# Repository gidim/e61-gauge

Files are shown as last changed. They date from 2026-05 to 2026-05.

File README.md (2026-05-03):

# E61 Gauge

An analog temperature gauge for E61 espresso machines. A custom PCB drives a VID6606 stepper motor gauge needle, reading temperature from an NTC thermistor. The gauge connects via BLE to a web app for calibration and real-time monitoring.

The dial has a non-linear scale (0–150°C) with an expanded green zone at 92–97°C for precision in the critical temperature range.

<p align="center">
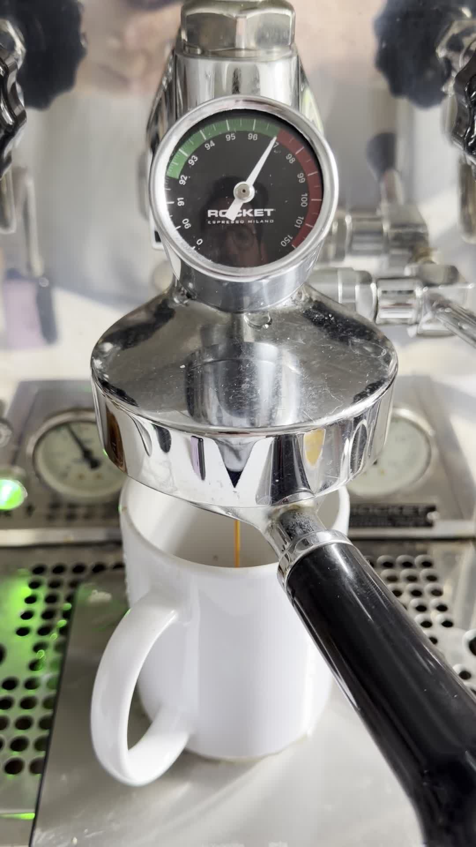
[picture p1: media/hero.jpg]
  
</p>

<p align="center">
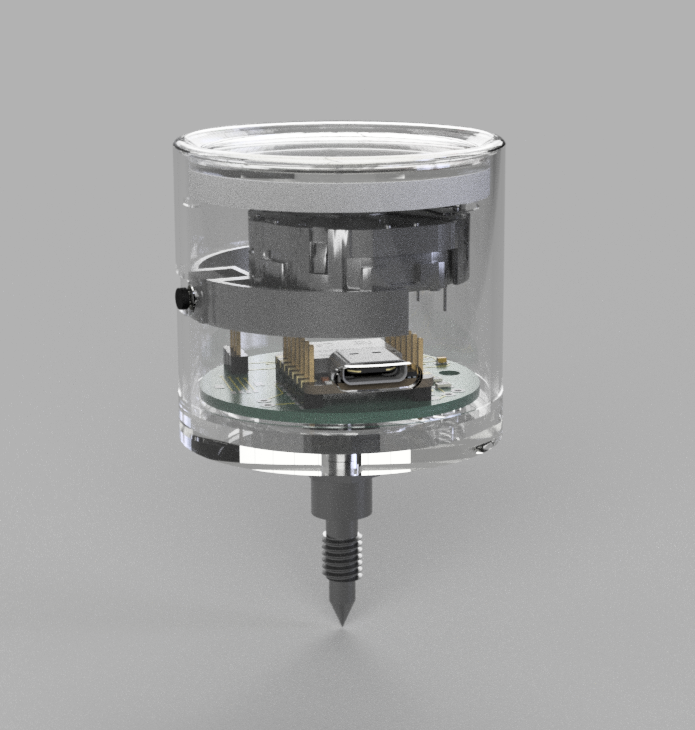
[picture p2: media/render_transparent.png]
  
  &nbsp;
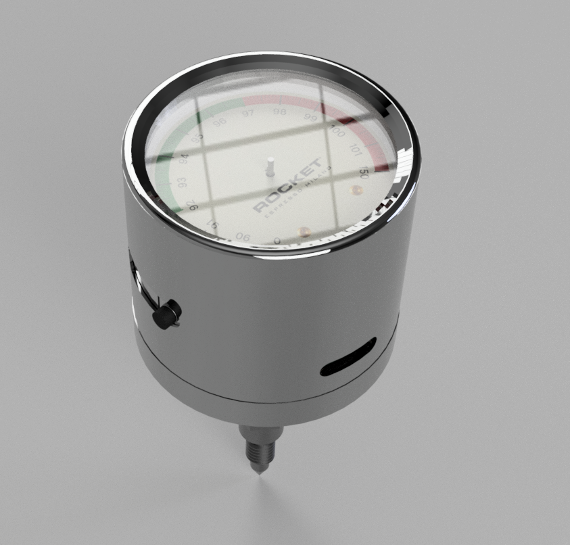
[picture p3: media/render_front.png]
  
  &nbsp;
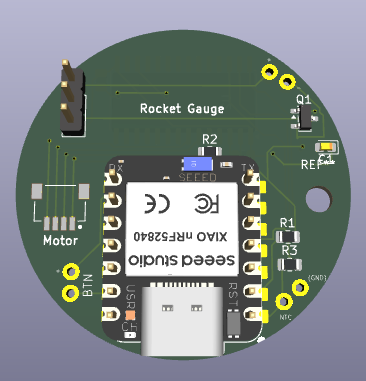
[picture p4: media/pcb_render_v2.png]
  
  &nbsp;
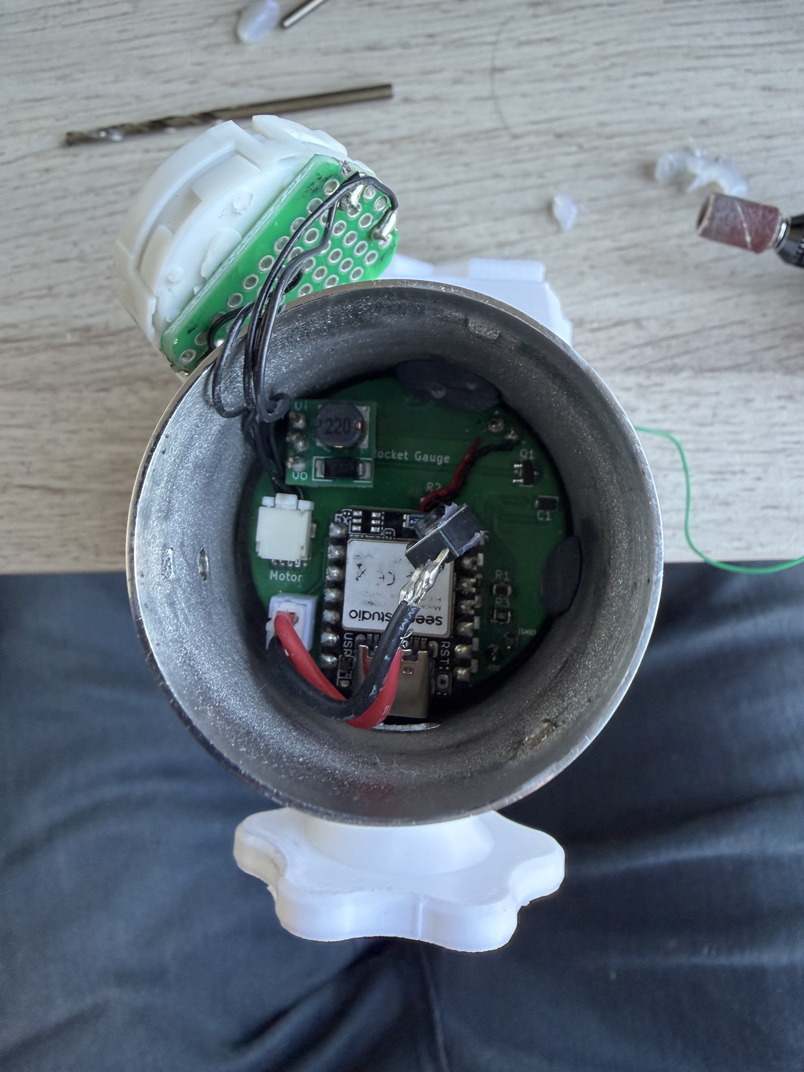
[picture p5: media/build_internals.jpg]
  
</p>

<p align="center">
  <a href="media/demo.mov">▶ Watch demo video</a>
</p>

---

## Hardware

Built around a **Seeed Studio XIAO nRF52840**. Key components:

- VID6606 stepper driver (SOIC-28) driving the gauge needle
- 100kΩ NTC thermistor for temperature sensing
- 2N2222A transistor switching a 5V boost converter
- Momentary button for power management (deep sleep after 10 min idle)
- JST connector for the stepper motor coils

The PCB was custom manufactured and assembled. The dial face is a custom design with a non-linear scale — the green zone (92–97°C) is expanded for precision while the cold and hot extremes are compressed. The SVG is in `hardware/dial_face.svg`. KiCad source files, schematic, and BOM are in `hardware/`.

## Enclosure

The enclosure was SLM (selective laser melting) 3D printed in metal and hand-sanded to achieve the chrome-like finish. Fusion 360 source (`enclosure/gauge_enclosure.f3z`), STEP, and STL files are in `enclosure/`.

### KiCad libraries

The schematic uses two non-standard libraries included in `libraries/`:

- `XIAO_nRF52840.pretty/` — footprint for the XIAO nRF52840 module
- `Seeed_Studio_XIAO_Series/` — schematic symbol

Add both to your KiCad library paths before opening the project.

## Firmware

Arduino sketch in `firmware/gauge/`. Uses the Adafruit nRF52 BSP.

**Dependencies** (install via Arduino Library Manager):
- `Adafruit TinyUSB`
- `Adafruit nRF52` BSP (includes `bluefruit`, `Adafruit_LittleFS`, `InternalFileSystem`)
- `AccelStepper`

The gauge supports BLE serial commands for calibration, homing, sweep tests, and configuration. See `firmware/gauge/commands.h` for the full command set.

## Web App

A Web Bluetooth app in `webapp/` — open `index.html` in Chrome (Android, macOS, or Windows). iOS Safari does not support Web Bluetooth.

Connect to the gauge over BLE to monitor temperature, set calibration points, and control the needle.

## Tools

Python utilities in `tools/` for serial-based development and testing.

```
pip install -r tools/requirements.txt
python tools/serial_terminal.py
```

## vid6606

`vid6606/` contains a standalone sweep demo sketch and a copy of the [SwitecX25](https://github.com/clearwater/SwitecX25) stepper library used for the VID6606 driver.

## test_ntc_sketch

A minimal Arduino sketch for validating NTC thermistor readings independently of the main firmware.

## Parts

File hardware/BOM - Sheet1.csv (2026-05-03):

Reference | Qty | Value | Assembly Status | Exclude from BOM | Footprint | Manufacturer | MPN | Datasheet
Battery1 | 1 | Wire Connection | DNP/Hand Solder |  | TestPoint:THT_2PAD_SOLDER_P5.08MM_GIDEON | N/A | N/A | ~
C1 | 1 | 10 µF | Aseemble |  | Capacitor_Tantalum_SMD:CP_EIA-1608-08_AVX-J | Vishay | 293D106X9010B2TE3
C2,C3 | 2 | 0.1uF | Assemble |  | Capacitor_SMD:C_0805_2012Metric | YAGEO | CC0805KRX7R9BB104 | ~
J1 | 1 | 5v Boost | Assemble |  | Connector_PinHeader_2.54mm:PinHeader_1x03_P2.54mm_Vertical | Molex | 22284030 | ~
M1 | 1 | Stepper_Motor_bipolar | Assemble |  | Connector_JST:JST_SM04B-SRSS-TB_LF__SN_ | JST | SM04B-NSHSS-TB(LF)(SN)
NTC1 | 1 | Wire Connection | DNP/Hand Solder | Exclude | TestPoint:THT_2PAD_SOLDER_P5.08MM_GIDEON |  |  | ~
Q1 | 1 | MMBT2222A | Assemble |  | Package_TO_SOT_SMD:SOT-23 | Onsemi | MMBT2222ALT1G | ~
R1,R2,R3 | 3 | 10k | Assemble |  | Resistor_SMD:R_0805_2012Metric | Yageo | RC0805FR-0710KL | ~
SW1 | 1 | Wire Connection | DNP/Hand Solder | Exclude | TestPoint:THT_2PAD_SOLDER_P5.08MM_GIDEON |  |  | ~
U2 | 1 | VID6606 | Assemble |  | Package_SO:SOIC-28W_7.5x17.9mm_P1.27mm | STI | STI6606Z
U3 | 1 | XIAO-nRF52840-DIP | DNP/Hand Solder | Exclude | XIAO_nRF52840:XIAO-nRF52840-DIP

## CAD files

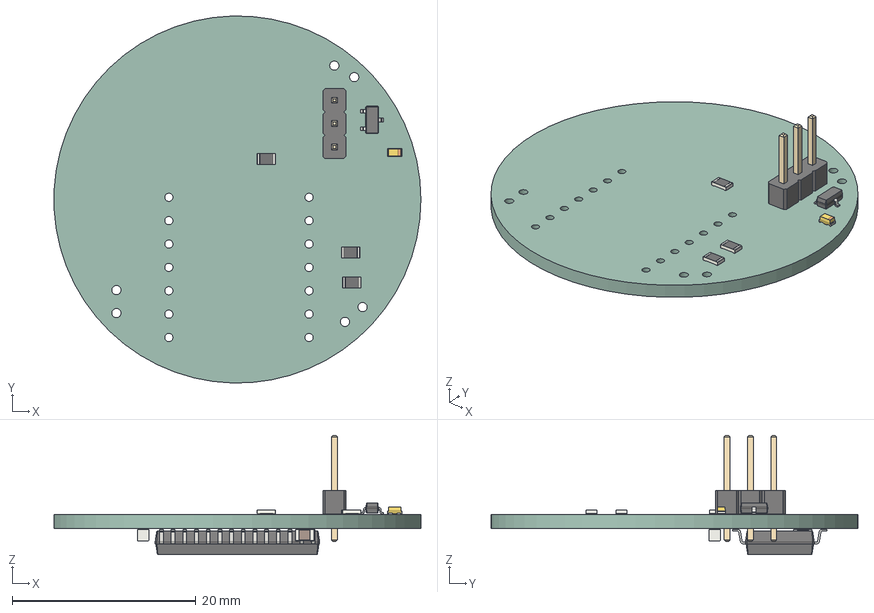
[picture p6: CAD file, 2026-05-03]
enclosure/gauge_enclosure.step
39.9 x 39.9 x 13.0 mm
PinHeader_1x03_P2.54mm_Vertical
SOT-23
R_0805_2012Metric x 3
CP_EIA-1608-08_AVX-J
C_0805_2012Metric x 2
SOIC-28W_7.5x17.9mm_P1.27mm
chip_and_transistor_PCB

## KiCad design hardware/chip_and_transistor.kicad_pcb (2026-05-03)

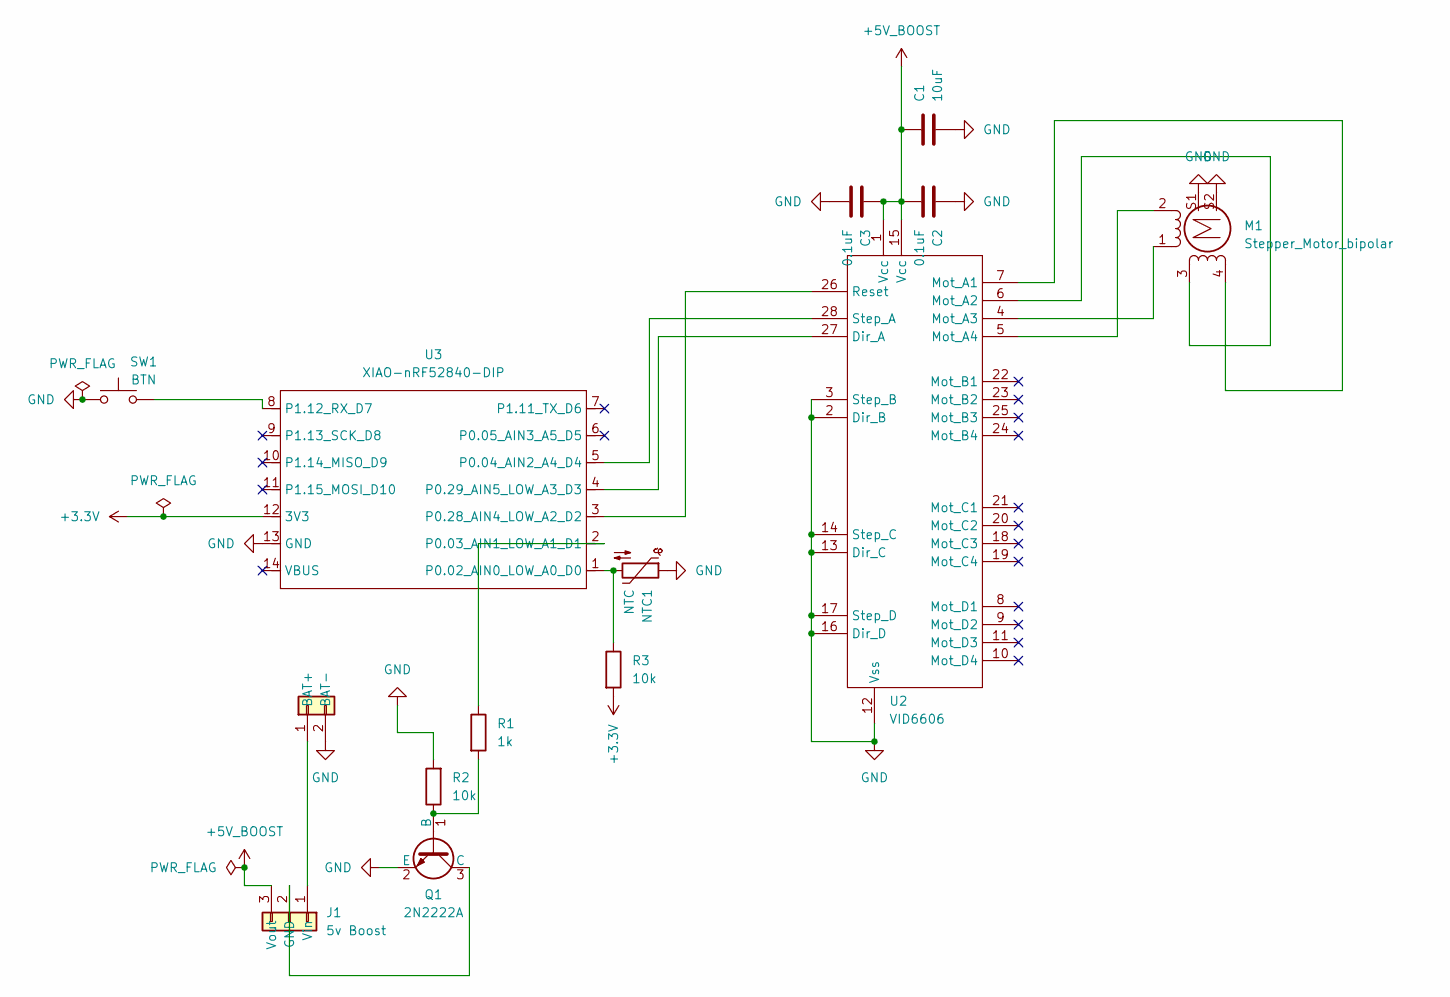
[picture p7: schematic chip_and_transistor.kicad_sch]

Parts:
Battery1: Battery; THT_2PAD_SOLDER_P5.08MM_GIDEON
C1: 10uF; CP_EIA-1608-08_AVX-J; LCSC C3151625
C2, C3: 0.1uF; C_0805_2012Metric; LCSC C49678
J1: 5v Boost; PinHeader_1x03_P2.54mm_Vertical; LCSC C587036
M1: Stepper_Motor_bipolar; JST_SM04B-SRSS-TB_LF__SN_; LCSC C5329994
NTC1: NTC; THT_2PAD_SOLDER_P5.08MM_GIDEON
Q1: 2N2222A; SOT-23; LCSC C82460
R1: 1k; R_0805_2012Metric; LCSC C84376
R2, R3: 10k; R_0805_2012Metric; LCSC C84376
SW1: BTN; THT_2PAD_SOLDER_P5.08MM_GIDEON
U2: VID6606; SOIC-28W_7.5x17.9mm_P1.27mm; LCSC C9900148309
U3: XIAO-nRF52840-DIP

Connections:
+3.3V: R3.2, U3.12 (3V3)
+5V_BOOST: C1.1, C2.2, C3.1, J1.3 (Vout), U2.1 (Vcc), U2.15 (Vcc)
GND: Battery1.2 (BAT-), C1.2, C2.1, C3.2, M1.S1, M1.S2, NTC1.1, Q1.2 (E), R2.2, SW1.1, U2.2 (Dir_B), U2.3 (Step_B), U2.12 (Vss), U2.13 (Dir_C), U2.14 (Step_C), U2.16 (Dir_D), U2.17 (Step_D), U3.13 (GND)
unnamed: Battery1.1 (BAT+), J1.1 (Vin)
unnamed: J1.2 (GND), Q1.3 (C)
unnamed: M1.2 (-), U2.5 (Mot_A4)
unnamed: Q1.1 (B), R1.2, R2.1
unnamed: U2.27 (Dir_A), U3.4 (P0.29_AIN5_LOW_A3_D3)
unnamed: M1.4, U2.7 (Mot_A1)
unnamed: M1.3, U2.6 (Mot_A2)
unnamed: M1.1, U2.4 (Mot_A3)
unnamed: U2.26 (Reset), U3.3 (P0.28_AIN4_LOW_A2_D2)
unnamed: U2.28 (Step_A), U3.5 (P0.04_AIN2_A4_D4)
unnamed: NTC1.2, R3.1, U3.1 (P0.02_AIN0_LOW_A0_D0)
unnamed: R1.1, U3.2 (P0.03_AIN1_LOW_A1_D1)
unnamed: SW1.2, U3.8 (P1.12_RX_D7)

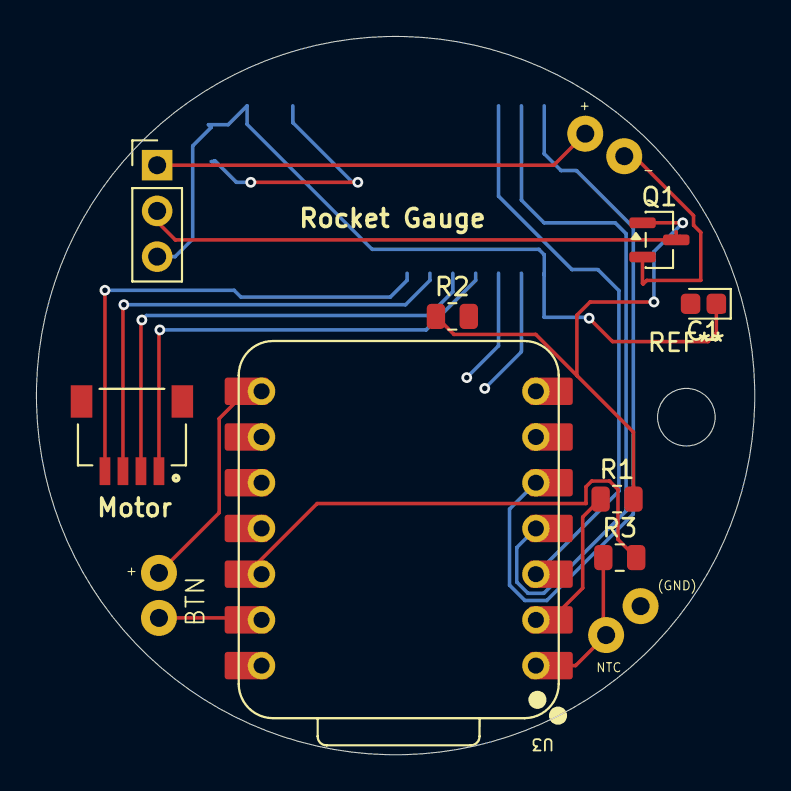
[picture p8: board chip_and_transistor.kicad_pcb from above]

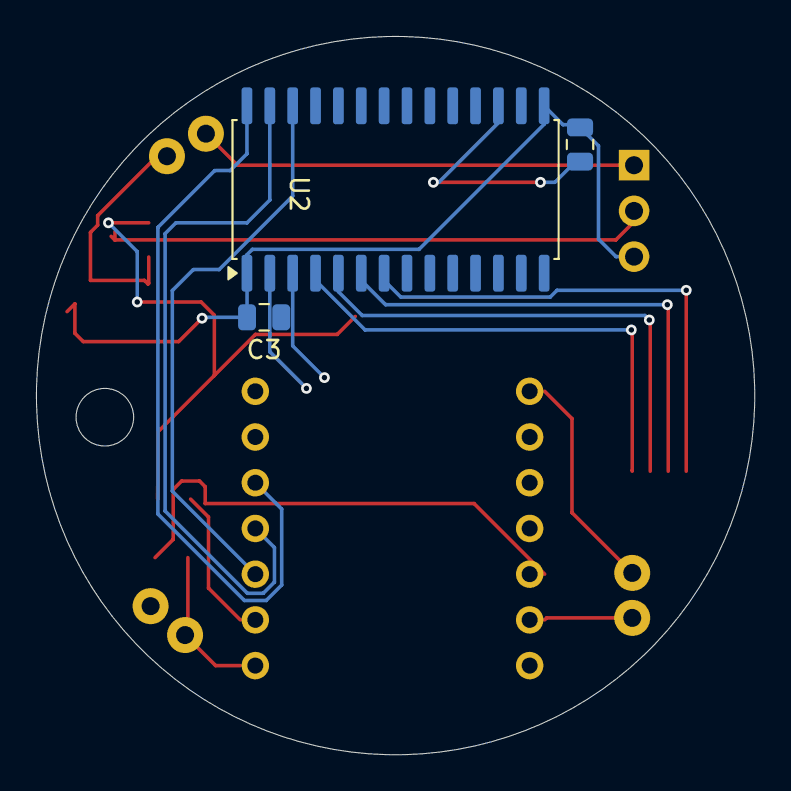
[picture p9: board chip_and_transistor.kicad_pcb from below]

Board: 2 copper layers, 39.9 x 39.9 mm, 14 parts (3 on the bottom side), 16 nets.

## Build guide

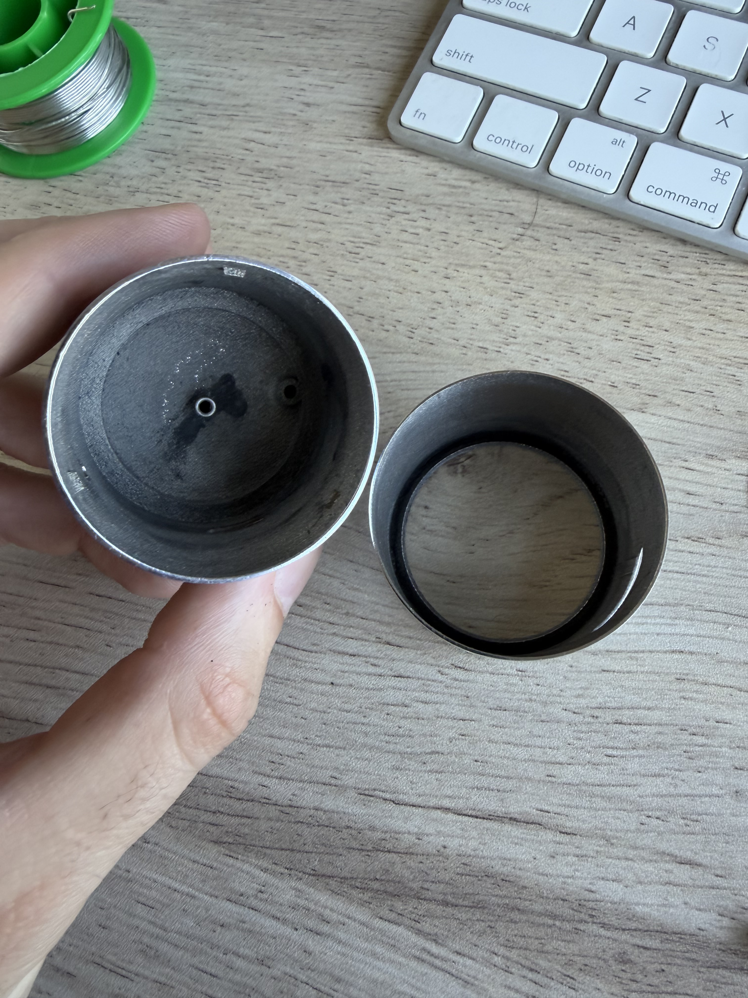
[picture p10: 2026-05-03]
media/build_enclosure_halves.jpg

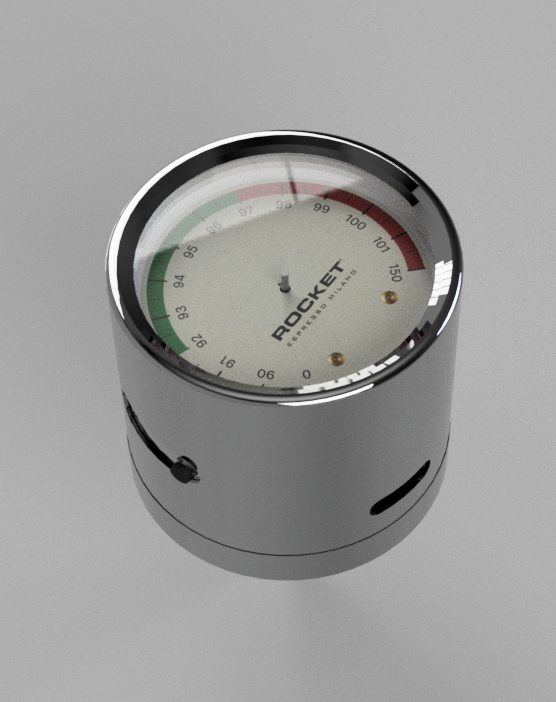
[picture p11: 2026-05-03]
media/render_assembly.png

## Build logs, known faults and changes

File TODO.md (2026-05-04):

# TODO

## Firmware
- [ ] Flash updated firmware (double-tap reset to enter DFU mode, then re-run `arduino-cli upload`)

## Hardware
- [ ] Replace battery with higher capacity unit
- [ ] Add transistor to NTC voltage divider circuit to cut it during sleep (saves ~30µA)

## Testing
- [ ] Verify sleep current draw after firmware flash (~35µA expected vs 50mA before)

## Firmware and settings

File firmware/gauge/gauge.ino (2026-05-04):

#include <Adafruit_TinyUSB.h>   // keeps USB serial alive on nRF52840
#include <math.h>
#include <bluefruit.h>          // Adafruit nRF52 BLE
#include <Adafruit_LittleFS.h>  // For flash storage
#include <InternalFileSystem.h> // For flash storage
#include <AccelStepper.h>       // For VID6606 stepper driver

using namespace Adafruit_LittleFS_Namespace;

// ---------------- hardware ----------------
// Boost converter control
const int boostPin = 1; // Controls 2N2222A transistor for 5V boost

// VID6606 stepper driver pins
const int enabPin = 2;  // RESET/ENABLE pin
const int dirPin = 3;   // DIR pin
const int stepPin = 4;  // STEP pin
const int NTC_PIN = A0; // thermistor input

// Power button
const int buttonPin = 7; // Momentary button (other leg to GND)

// Create stepper instance (step/direction driver)
AccelStepper myStepper(AccelStepper::DRIVER, stepPin, dirPin);

// ---------------- NTC params (match your working code) ----------------
const float SERIES_R      = 10000.0f;      // 10 kΩ series resistor
const float NTC_R0        = 100000.0f;     // 100 kΩ at 25 °C
const float NTC_T0_C      = 25.0f;         // nominal temp in °C
const float NTC_BETA      = 3950.0f;       // from datasheet
const float ADC_VREF      = 3.3f;          // ADC reference voltage
const int   ADC_MAX       = 4095;          // 12-bit ADC

// ---------------- stepper settings ----------------
const int STEPPER_MAX_SPEED = 2000;      // steps per second
const int STEPPER_ACCELERATION = 2400;   // steps per second^2

// ---------------- state ----------------
bool calibrationMode = false;  // false = regular mode, true = calibration mode
bool tempTestMode = false;     // false = silent, true = continuous temp printing
// Power management
unsigned long lastActivityTime = 0;
const unsigned long SLEEP_TIMEOUT_MS = 600000; // 10 minutes

// Button debounce
unsigned long lastButtonCheck = 0;
bool lastButtonState = HIGH;   // Pull-up: HIGH = not pressed
bool buttonPressed = false;

// ---------------- ZONE-BASED CALIBRATION FOR ROCKET GAUGE ----------------
// Actual dial: 0-150°C with green zone at 92-97°C (non-linear scale)
// Dial positions: 0, 90, 91, 92, 93, 94, 95, 96, 97, 98, 99, 100, 101, 150
const int MAX_CAL_COLD = 3;   // 90-92°C (red zone left, compressed on dial)
const int MAX_CAL_GREEN = 15; // 92-97°C (GREEN ZONE - expanded on dial, high precision)
const int MAX_CAL_HOT = 3;    // 97-101°C (red zone right, compressed on dial)

// Separate calibration arrays for each zone
float calCold_T[MAX_CAL_COLD], calGreen_T[MAX_CAL_GREEN], calHot_T[MAX_CAL_HOT];
int calCold_S[MAX_CAL_COLD], calGreen_S[MAX_CAL_GREEN], calHot_S[MAX_CAL_HOT];
int calColdCount = 0, calGreenCount = 0, calHotCount = 0;

// ---------------- Non-linear dial mapping ----------------
// Lookup table for known dial positions (will be calibrated)
// Dial shows: 0, 90, 91, 92, 93, 94, 95, 96, 97, 98, 99, 100, 101, 150
// Initial estimates - these will be replaced by calibration
const int DIAL_POINTS = 14;
const float dialTemps[DIAL_POINTS] = {0, 90, 91, 92, 93, 94, 95, 96, 97, 98, 99, 100, 101, 150};
// Initial step estimates (will be calibrated):
// 0-90: compressed (0-375 steps)
// 90-101: expanded (375-2625 steps) - critical range
// 101-150: compressed (2625-3000 steps)
int dialSteps[DIAL_POINTS] = {0, 375, 500, 750, 1125, 1500, 1875, 2250, 2625, 2700, 2775, 2850, 2925, 3000};

// ---------------- home offset ----------------
int homeOffset = 20;  // Default 20 steps forward after hitting stop

// ---------------- max steps ----------------
int maxSteps = 3000;  // Maximum steps for full dial range (configurable via MAXSTEPS command)

// ---------------- Flash Storage ----------------
File calFile(InternalFS);
const char calFilename[] = "/calibration_rocket.dat";

// ---------------- BLE UART ----------------
BLEUart bleuart;                 // Nordic UART Service
String usbLineBuf, bleLineBuf;   // line buffers for command parsing

// ---------------- Battery Monitor ----------------
// Note: Not using the Xiao library due to incorrect ADC constants
// Implementing our own battery reading based on official examples

#define VBAT_MV_PER_LSB   (0.73242188F)   // 3.0V ADC range and 12-bit ADC resolution = 3000mV/4096
#define VBAT_DIVIDER_COMP (2.96F)          // XIAO voltage divider compensation (1510/510)
#define REAL_VBAT_MV_PER_LSB (VBAT_DIVIDER_COMP * VBAT_MV_PER_LSB)

#define BAT_CHARGE_STATE 23 // LOW for charging, HIGH not charging

// Helpers to print to both USB Serial and BLE UART
void bothPrint(const String& s){
  Serial.print(s);
  if(Bluefruit.connected()){
    bleuart.print(s);
  }
}
void bothPrint(const char* s){
  Serial.print(s);
  if(Bluefruit.connected()){
    bleuart.print(s);
  }
}
void bothPrint(float v, int digits){
  Serial.print(v, digits);
  if(Bluefruit.connected()){
    bleuart.print(v, digits);
  }
}
void bothPrint(int v){
  Serial.print(v);
  if(Bluefruit.connected()){
    bleuart.print(v);
  }
}
void bothPrintln(const String& s=""){
  Serial.println(s);
  if(Bluefruit.connected()){
    bleuart.println(s);
  }
}
void bothPrintf(const char* fmt, ...){
  char buf[120];
  va_list ap;
  va_start(ap, fmt);
  vsnprintf(buf, sizeof(buf), fmt, ap);
  va_end(ap);
  Serial.print(buf);
  if(Bluefruit.connected()){
    bleuart.print(buf);
  }
}

// ---------- motor drive ----------
void moveToSteps(int target) {
  // Move to target position with AccelStepper (non-blocking)
  myStepper.moveTo(target);
}

// ---------- homing ----------
void homeToStop(){
  // Move CCW far enough to definitely hit the mechanical stop
  // Motor will stall against stop, which is fine - this ensures zero position
  myStepper.runToNewPosition(-4000);

  // Set this as zero, then move forward by the calibrated offset
  myStepper.setCurrentPosition(0);
  myStepper.runToNewPosition(homeOffset);
  myStepper.setCurrentPosition(0);  // This is now our zero position

  bothPrint("Homed with offset: ");
  bothPrintln(String(homeOffset));
}

// ---------- button handling ----------
void checkButton() {
  unsigned long now = millis();
  if (now - lastButtonCheck < 50) return; // 50ms debounce interval
  lastButtonCheck = now;

  bool currentState = digitalRead(buttonPin);
  if (lastButtonState == HIGH && currentState == LOW) {
    buttonPressed = true; // Falling edge: button pressed
  }
  lastButtonState = currentState;
}

// ---------- power management ----------
void sleepNow(){
  bothPrintln("Going to sleep...");
  delay(100); // Allow message to send

  // De-energize motor: disable driver and release all pins to stop coil current
  myStepper.disableOutputs();
  digitalWrite(enabPin, LOW);
  digitalWrite(dirPin, LOW);
  digitalWrite(stepPin, LOW);
  delay(50);

  // Turn off boost
  digitalWrite(boostPin, LOW);

  // Disable battery voltage divider
  pinMode(VBAT_ENABLE, OUTPUT);
  digitalWrite(VBAT_ENABLE, HIGH);

  // Disconnect BLE if connected
  if(Bluefruit.connected()){
    Bluefruit.disconnect(0);
    delay(200);
  }

  // Stop BLE advertising
  Bluefruit.Advertising.stop();
  delay(200);

  // Turn off Serial
  Serial.end();

  // Configure button pin for wake from System OFF
  nrf_gpio_cfg_sense_input(g_ADigitalPinMap[buttonPin],
                           NRF_GPIO_PIN_PULLUP,
                           NRF_GPIO_PIN_SENSE_LOW);

  // Shut down SoftDevice to release hardware ownership, then
  // write directly to the power register - guaranteed, cannot fail
  sd_softdevice_disable();
  NRF_POWER->SYSTEMOFF = 1;

  // Unreachable - chip is off
  while(1);
}

// ---------- Flash storage functions ----------
void saveCalibration(){
  if(calFile.open(calFilename, FILE_O_WRITE)){
    // Save home offset
    calFile.write((uint8_t*)&homeOffset, sizeof(homeOffset));

    // Save max steps
    calFile.write((uint8_t*)&maxSteps, sizeof(maxSteps));
    
    // Save cold zone (85-92°C)
    calFile.write((uint8_t*)&calColdCount, sizeof(calColdCount));
    if(calColdCount > 0) {
      calFile.write((uint8_t*)calCold_T, sizeof(float) * calColdCount);
      calFile.write((uint8_t*)calCold_S, sizeof(int) * calColdCount);
    }
    
    // Save green zone (92-98°C)
    calFile.write((uint8_t*)&calGreenCount, sizeof(calGreenCount));
    if(calGreenCount > 0) {
      calFile.write((uint8_t*)calGreen_T, sizeof(float) * calGreenCount);
      calFile.write((uint8_t*)calGreen_S, sizeof(int) * calGreenCount);
    }
    
    // Save hot zone (98-105°C)
    calFile.write((uint8_t*)&calHotCount, sizeof(calHotCount));
    if(calHotCount > 0) {
      calFile.write((uint8_t*)calHot_T, sizeof(float) * calHotCount);
      calFile.write((uint8_t*)calHot_S, sizeof(int) * calHotCount);
    }
    
    calFile.close();
    bothPrintln("Calibration saved to flash");
  }else{
    bothPrintln("Failed to save calibration");
  }
}

void loadCalibration(){
  if(calFile.open(calFilename, FILE_O_READ)){
    // Load home offset
    int bytesRead = calFile.read((uint8_t*)&homeOffset, sizeof(homeOffset));
    if(bytesRead == sizeof(homeOffset)){
      bothPrint("Loaded home offset: ");
      bothPrintln(String(homeOffset));
    }

    // Load max steps
    bytesRead = calFile.read((uint8_t*)&maxSteps, sizeof(maxSteps));
    if(bytesRead == sizeof(maxSteps)){
      bothPrint("Loaded max steps: ");
      bothPrintln(String(maxSteps));
    }
    
    // Load cold zone
    calFile.read((uint8_t*)&calColdCount, sizeof(calColdCount));
    if(calColdCount > 0 && calColdCount <= MAX_CAL_COLD){
      calFile.read((uint8_t*)calCold_T, sizeof(float) * calColdCount);
      calFile.read((uint8_t*)calCold_S, sizeof(int) * calColdCount);
    }
    
    // Load green zone
    calFile.read((uint8_t*)&calGreenCount, sizeof(calGreenCount));
    if(calGreenCount > 0 && calGreenCount <= MAX_CAL_GREEN){
      calFile.read((uint8_t*)calGreen_T, sizeof(float) * calGreenCount);
      calFile.read((uint8_t*)calGreen_S, sizeof(int) * calGreenCount);
    }
    
    // Load hot zone
    calFile.read((uint8_t*)&calHotCount, sizeof(calHotCount));
    if(calHotCount > 0 && calHotCount <= MAX_CAL_HOT){
      calFile.read((uint8_t*)calHot_T, sizeof(float) * calHotCount);
      calFile.read((uint8_t*)calHot_S, sizeof(int) * calHotCount);
    }
    
    calFile.close();
    bothPrintln("Calibration loaded from flash");

  }else{
    bothPrintln("No saved calibration found, using defaults");
    homeOffset = 20;
    maxSteps = 3000;
  }
}

// ---------- calibration helpers ----------
void sortZone(float temps[], int steps[], int count){
  for(int i=1;i<count;i++){
    float t=temps[i]; int s=steps[i]; int j=i-1;
    while(j>=0 && temps[j]>t){ 
      temps[j+1]=temps[j]; steps[j+1]=steps[j]; j--; 
    }
    temps[j+1]=t; steps[j+1]=s;
  }
}

// Helper function for interpolation
int interpolatePoints(float t, float temps[], int steps[], int count) {
  if (count == 0) return 0;
  if (count == 1) return steps[0];
  
  // Check if before first point
  if (t <= temps[0]) return steps[0];
  // Check if after last point
  if (t >= temps[count-1]) return steps[count-1];
  
  // Find bounding points
  for(int i = 0; i < count - 1; i++) {
    if (temps[i] <= t && temps[i+1] >= t) {
      float ratio = (t - temps[i]) / (temps[i+1] - temps[i]);
      return steps[i] + int(ratio * (steps[i+1] - steps[i]) + 0.5);
    }
  }
  
  return steps[count - 1];
}

// Non-linear temperature to step mapping using dial lookup table
// Uses calibration data if available, otherwise interpolates from dial positions
int stepsForTemp(float t) {
  // Clamp to dial range
  if (t < 0.0) return 0;
  if (t > 150.0) return maxSteps;
  
  // Check for calibration data in critical zones (92-97°C green zone)
  if (t >= 92.0 && t <= 97.0) {
    // GREEN ZONE - use calibration if available
    if (calGreenCount > 0) {
      return interpolatePoints(t, calGreen_T, calGreen_S, calGreenCount);
    }
  }
  else if (t >= 90.0 && t < 92.0) {
    // Cold zone (90-92°C) - use calibration if available
    if (calColdCount >= 2) {
      return interpolatePoints(t, calCold_T, calCold_S, calColdCount);
    }
  }
  else if (t > 97.0 && t <= 101.0) {
    // Hot zone (97-101°C) - use calibration if available
    if (calHotCount >= 2) {
      return interpolatePoints(t, calHot_T, calHot_S, calHotCount);
    }
  }
  
  // No calibration data or outside calibrated zones - use dial lookup table
  // Find the two dial points that bracket this temperature
  for (int i = 0; i < DIAL_POINTS - 1; i++) {
    if (t >= dialTemps[i] && t <= dialTemps[i + 1]) {
      // Linear interpolation between dial points
      float ratio = (t - dialTemps[i]) / (dialTemps[i + 1] - dialTemps[i]);
      int steps = dialSteps[i] + int(ratio * (dialSteps[i + 1] - dialSteps[i]) + 0.5);
      return steps;
    }
  }

  // Fallback (shouldn't reach here due to clamping above)
  return maxSteps;
}

void listCal(){
  bothPrintln("=== ROCKET GAUGE CALIBRATION ===");
  
  bothPrint("COLD ZONE (90-92C red): ");
  bothPrint(calColdCount); bothPrintln(" points");
  for(int i=0;i<calColdCount;i++){
    bothPrint("  "); bothPrint(calCold_T[i],1);
    bothPrint("C -> "); bothPrintln(String(calCold_S[i]));
  }
  
  bothPrint("GREEN ZONE (92-97C): ");
  bothPrint(calGreenCount); bothPrintln(" points");
  for(int i=0;i<calGreenCount;i++){
    bothPrint("  "); bothPrint(calGreen_T[i],1);
    bothPrint("C -> "); bothPrintln(String(calGreen_S[i]));
  }
  
  bothPrint("HOT ZONE (97-101C red): ");
  bothPrint(calHotCount); bothPrintln(" points");
  for(int i=0;i<calHotCount;i++){
    bothPrint("  "); bothPrint(calHot_T[i],1);
    bothPrint("C -> "); bothPrintln(String(calHot_S[i]));
  }
  
  bothPrint("HOME OFFSET: ");
  bothPrintln(String(homeOffset));

  bothPrint("MAX STEPS: ");
  bothPrintln(String(maxSteps));
}

// ---------- Battery read ----------
float readBatteryVoltage() {
  // Enable battery voltage reading
  pinMode(VBAT_ENABLE, OUTPUT);
  digitalWrite(VBAT_ENABLE, LOW);

  // Set the analog reference to 3.0V (default = 3.6V)
  analogReference(AR_INTERNAL_3_0);
  analogReadResolution(12);

  // Let the ADC settle
  delay(1);

  // Read battery voltage
  float raw = analogRead(PIN_VBAT);

  // Disable battery voltage reading
  digitalWrite(VBAT_ENABLE, HIGH);

  // Restore ADC settings
  analogReference(AR_DEFAULT);
  analogReadResolution(12);

  // Convert to mV with voltage divider compensation
  return raw * REAL_VBAT_MV_PER_LSB;
}

bool isBatteryCharging() {
  pinMode(BAT_CHARGE_STATE, INPUT);
  return digitalRead(BAT_CHARGE_STATE) == LOW;
}

// ---------- NTC read ----------
// Voltage divider: Series resistor to 3V3, NTC to GND
float readNTCTemp(){
  int adc = analogRead(NTC_PIN);

  // Safety check: if ADC reading is too low, return a safe default
  if(adc < 10) {
    return 25.0f;  // Return room temperature as safe default
  }

  float v = adc * ADC_VREF / ADC_MAX;

  // Safety check: if voltage is near VREF, return safe default
  if(v >= (ADC_VREF - 0.01f)) {
    return 25.0f;  // Return room temperature as safe default
  }

  float r = SERIES_R * v / (ADC_VREF - v);  // Series resistor to 3V3, NTC to GND
  
  // Safety check: if resistance is invalid, return safe default
  if(r <= 0.0f || r > 10000000.0f || isnan(r) || isinf(r)) {
    return 25.0f;  // Return room temperature as safe default
  }
  
  float tK = 1.0f / (logf(r / NTC_R0) / NTC_BETA + 1.0f / (NTC_T0_C + 273.15f));
  float tC = tK - 273.15f;
  
  // Safety check: if temperature is invalid, return safe default
  if(tC < -50.0f || tC > 200.0f || isnan(tC) || isinf(tC)) {
    return 25.0f;  // Return room temperature as safe default
  }
  
  return tC;
}

// ---------- BLE setup helpers ----------
void startAdv(){
  Bluefruit.Advertising.addFlags(BLE_GAP_ADV_FLAGS_LE_ONLY_GENERAL_DISC_MODE);
  Bluefruit.Advertising.addTxPower();
  Bluefruit.Advertising.addService(bleuart);
  Bluefruit.ScanResponse.addName();
  Bluefruit.Advertising.restartOnDisconnect(true);
  Bluefruit.Advertising.setInterval(32, 244);
  Bluefruit.Advertising.setFastTimeout(0);
  Bluefruit.Advertising.start(0);
}

// Include command interface after all function definitions
#include "commands.h"

// ---------- setup ----------
void setup(){
  // Button pin first - needed for wake-hold detection
  pinMode(buttonPin, INPUT_PULLUP);

  // Wait for button release (prevents immediate re-sleep if held from wake)
  while (digitalRead(buttonPin) == LOW) {
    delay(10);
  }
  delay(50); // Extra debounce after release

  // Initialize boost converter control
  pinMode(boostPin, OUTPUT);
  digitalWrite(boostPin, HIGH);
  delay(100); // Wait for boost to stabilize

  // Initialize VID6606 stepper driver pins
  pinMode(enabPin, OUTPUT);
  pinMode(dirPin, OUTPUT);
  pinMode(stepPin, OUTPUT);

  // Enable the VID6606 driver
  digitalWrite(enabPin, LOW);
  delay(100);
  digitalWrite(enabPin, HIGH);

  pinMode(NTC_PIN, INPUT);
  analogReadResolution(12);

  // Configure stepper speed and acceleration
  myStepper.setMaxSpeed(STEPPER_MAX_SPEED);
  myStepper.setAcceleration(STEPPER_ACCELERATION);

  // USB Serial with timeout for battery
  Serial.begin(115200);
  unsigned long startTime = millis();
  while(!Serial && millis() - startTime < 1000) {
    delay(10);
  }

  // Initialize flash storage
  InternalFS.begin();

  // BLE setup
  Bluefruit.autoConnLed(true);
  Bluefruit.begin();
  Bluefruit.setTxPower(4);
  Bluefruit.setName("Rocket Gauge");
  bleuart.begin();
  startAdv();

  // Load calibration
  loadCalibration();

  // Check reset reason for debug logging (must use SoftDevice API, not direct register)
  uint32_t resetReason = 0;
  sd_power_reset_reason_get(&resetReason);
  sd_power_reset_reason_clr(resetReason);

  bothPrintln("=== ROCKET ESPRESSO GAUGE ===");
  if (resetReason & 0x00010000) {
    bothPrintln("Woke from deep sleep (GPIO)");
  } else if (resetReason == 0) {
    bothPrintln("Power-on reset");
  } else {
    bothPrint("Reset reason: 0x");
    char buf[9];
    snprintf(buf, sizeof(buf), "%08lX", (unsigned long)resetReason);
    bothPrintln(buf);
  }

  bothPrintln("Homing...");
  homeToStop();

  lastActivityTime = millis();
  lastButtonCheck = millis();  // Prevent immediate button trigger
  lastButtonState = digitalRead(buttonPin); // Sync to actual pin state
  bothPrintln("Ready! Type HELP for commands");
}

// ---------- loop ----------
void loop(){
  // IMPORTANT: Must call run() continuously for AccelStepper to work
  myStepper.run();

  // Check button - sleep on press (skip first 2s after boot)
  if (millis() > 2000) {
    checkButton();
  }
  if (buttonPressed) {
    buttonPressed = false;
    sleepNow(); // Does not return
  }

  // Auto-sleep after inactivity
  if (millis() - lastActivityTime >= SLEEP_TIMEOUT_MS) {
    bothPrintln("Auto-sleep: 10 min inactivity");
    sleepNow(); // Does not return
  }

  // Read commands
  pumpUsbSerial();
  pumpBleSerial();

  // Auto temperature control only in regular mode (already awake if we got here)
  if(!calibrationMode){
    static unsigned long lastUpdate=0;
    unsigned long now=millis();
    if(now - lastUpdate >= 167){
      lastUpdate=now;

      float t = readNTCTemp();
      int target = stepsForTemp(t);
      int currentPos = myStepper.currentPosition();

      // Safety check: ensure target is within valid range
      if(target < 0) target = 0;
      if(target > maxSteps) target = maxSteps;

      // Only move if difference is significant and target is reasonable
      if(abs(target - currentPos) > 2 && target >= 0 && target <= maxSteps){
        moveToSteps(target);
      }

      // Print temp continuously if in TEMP TEST mode
      if(tempTestMode){
        bothPrint("Temp: ");
        bothPrint(t,1);
        bothPrint("C -> ");
        bothPrint(target);
        bothPrint(" steps");

        // Show zone (dial range: 0-150°C, green zone: 92-97°C)
        if(t < 0) bothPrint(" (Below dial)");
        else if(t < 90) bothPrint(" (Below critical)");
        else if(t < 92) bothPrint(" (COLD)");
        else if(t <= 97) bothPrint(" (GREEN)");
        else if(t <= 101) bothPrint(" (HOT)");
        else if(t <= 150) bothPrint(" (Above critical)");
        else bothPrint(" (Above dial)");

        bothPrintln("");
      }
    }
  }
}

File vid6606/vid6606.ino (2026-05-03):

/*
  VID6606 stepper driver sweep demo using AccelStepper library
  Adapted from STI6606z example code for VID6606 driver
  Sweeps the needle back and forth with smooth acceleration
*/

#include <AccelStepper.h>
#include <elapsedMillis.h>

// Motor Connections for VID6606 driver
const int enabPin = 2;  // RESET/ENABLE pin
const int dirPin = 3;   // DIR pin
const int stepPin = 4;  // STEP pin

// Create stepper instance (step/direction driver)
AccelStepper myStepper(AccelStepper::DRIVER, stepPin, dirPin);

elapsedMillis sweepTime;
const int sweepInterval = 2000;   // sweep interval in milliseconds

const long STEPS_PER_REVOLUTION = 315 * 12;   // for 315 degrees with twelve step microstepping
const long SWEEP_RANGE = 3000;    // sweep range in steps

bool sweepingUp = true;

void setup() {
  pinMode(enabPin, OUTPUT);
  digitalWrite(enabPin, LOW);
  delay(100);
  digitalWrite(enabPin, HIGH);    // enable the controller

  myStepper.setMaxSpeed(2000);
  myStepper.setAcceleration(2400);

  // Zero the motor
  myStepper.runToNewPosition(-4000);   // run backwards to find zero
  myStepper.setCurrentPosition(0);

  // Initial position
  myStepper.runToNewPosition(100);
  delay(500);

  sweepTime = 0;
}

void loop() {
  // Check if it's time to change sweep direction
  if (sweepTime >= sweepInterval) {
    sweepTime = 0;

    if (sweepingUp) {
      myStepper.moveTo(SWEEP_RANGE);
      sweepingUp = false;
    } else {
      myStepper.moveTo(100);
      sweepingUp = true;
    }
  }

  // Always run the stepper (handles acceleration automatically)
  myStepper.run();
}

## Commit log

2026-05-03 Initial commit: firmware, hardware, webapp, libraries
    [BOM - Sheet1.csv, chip_and_transistor.kicad_pcb, chip_and_transistor.kicad_sch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]
2026-05-03 Add Fusion 360 enclosure model
2026-05-03 Move enclosure files to top-level enclosure/
    [gauge_enclosure.step]
2026-05-03 Add enclosure section to README
2026-05-03 Mention custom PCB and SLM printed enclosure in README
2026-05-03 Add PCB 3D render to media and README
2026-05-03 Replace PCB render with cropped version
2026-05-03 Rename PCB render to bust GitHub image cache
2026-05-03 Update README to use renamed PCB render
2026-05-04 Disable VBAT_ENABLE before deep sleep to prevent battery divider drain
    [gauge.ino]
2026-05-04 Fix sleep: disable SoftDevice before System OFF, de-energize motor coils
    [gauge.ino]
